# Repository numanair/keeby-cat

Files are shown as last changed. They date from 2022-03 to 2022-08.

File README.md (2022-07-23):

# Keeby Cat

This is the hardware repository for the Keeby Cat macropad. Developement is ongoing.

## Intro

Keeby Cat is a highly configurable macropad with multiple fader and knob layouts. The "standard" build features 3x4 keys with a rotary encoder and an 128x32 pixel OLED display. A full keyswitch build is 3x5 keys with the top row offset vertically by 0.25u. Up to five rotary encoders can be used in specified locations. One to three faders (linear potentiometers) can be used in place of the lower key columns.

## Firmware

Vial is the standard firmware for Keeby Cat as it allows key and encoder reassignment without recompiling firmware.
Firmware source is located here: [github.com/numanair/vial-qmk](https://github.com/numanair/vial-qmk/tree/vial/keyboards/returntoparadise/keeby_cat)  
**Note:** Firmware has not yet been completed for all variations. As such not all variants have been tested yet. However, the groundwork is there and it should not be too complicated to create these firmware variations.

## Layouts and Configurations

The default configuration is 3x4 keys with a single knob and an OLED screen.

The maximum keyswitch layout is 3x5.

### Rotary Encoder Knobs

Nine special key locations can accept encoder knobs, however only five knobs can be wired up at once.

Potential knob locations are:  
The left and right columns of the lower 4 keys, but with only one from each *row* being installed.
The top left corner.

### OLED Screen

An optional display can show layer information, key-states, and graphics. It replaces the top right pair of keyswitches.

## Cases

Two types of cases are available. The low-profile option is more minimal in material usage and features a 3-degree tilt. The high-profile case (`keeby_cat_case_retro-hi_v1.0.FCStd`) has a 5-degree tilt, but is actually slightly lower profile at the front. USB port placement on the high-profile case is currently more refined. It is designed for a Blue Pill board with a mid-mount micro USB port. These refinements will eventually be integrated into the low-profile case as well. To modify these CAD files, please use [realthunder's FreeCAD fork, stable build 2022.07.09.](https://github.com/realthunder/FreeCAD/releases/tag/2022.07.09-edge)

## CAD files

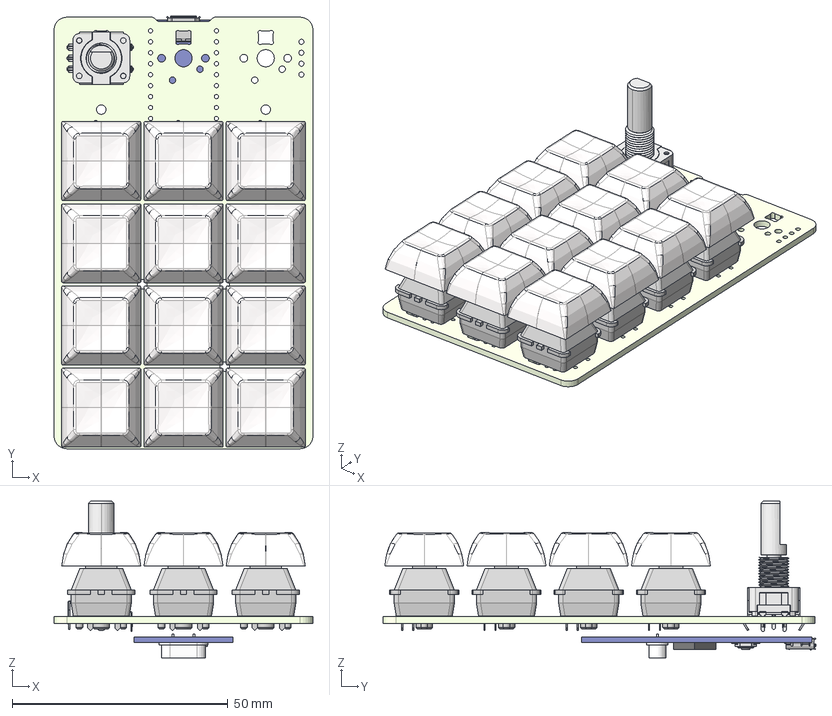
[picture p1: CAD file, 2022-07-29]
FreeCAD Assembly/keeby_cat_electronics_v1.0.FCStd
60.0 x 100.2 x 36.3 mm
Pcb_61fa
SW4_cherry_mx v1_b31d9dcab5e3 x 12
SW4_Keycap_adjusted v39_b31d9dcab5e3[2] x 24
EN4_PEC11-4220F-S0024_05183b338953 x 2
Oscillator_HC-49/S v1
STM32F103C8T6_BluePill_Board v6
STM32_LQFP48 v3
Tactile_SMD_5x5mm v1
micro_usb_socket v1

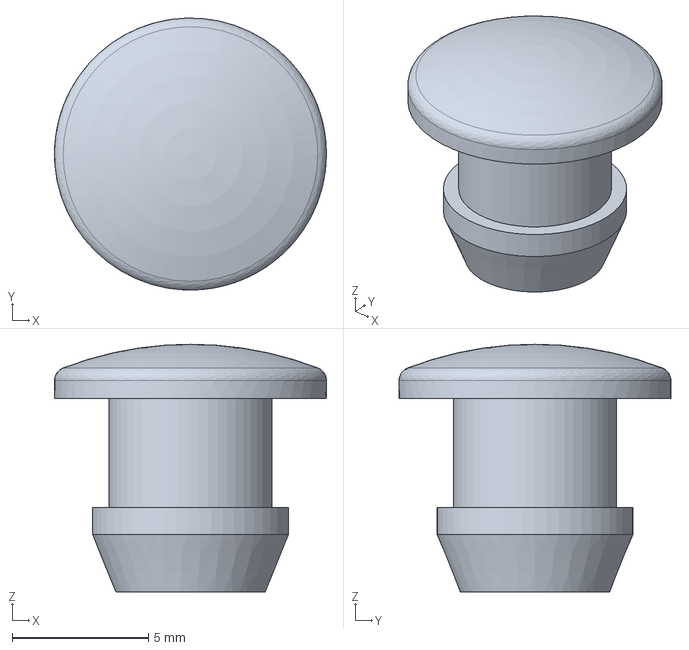
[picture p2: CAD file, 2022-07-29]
FreeCAD Assembly/silicone_stopper_foot.FCStd
10.00 x 10.00 x 9.10 mm

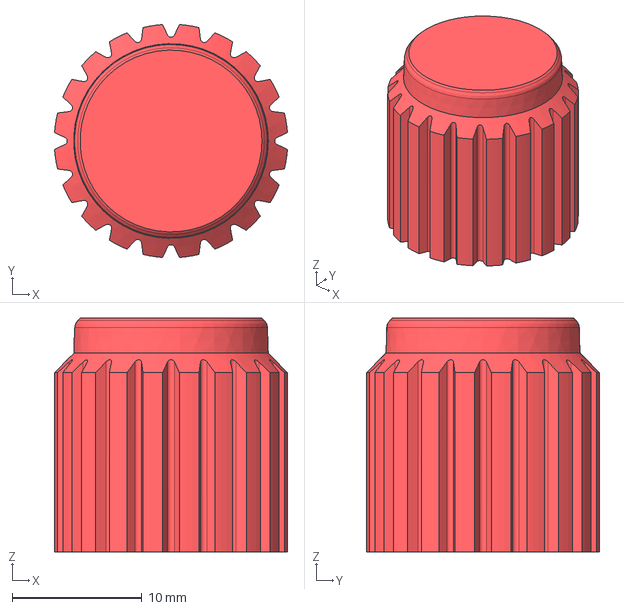
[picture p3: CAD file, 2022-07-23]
FreeCAD Assembly/knob_brute.FCStd
18.0 x 18.0 x 18.0 mm

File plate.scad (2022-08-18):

// include <NopSCADlib/core.scad>
include <NopSCADlib/lib.scad>
include <Chamfers-for-OpenSCAD/Chamfer.scad>

$fn=24;

plate_thick=5 - 0.2;
plate_thin=1.5;
chamfer_size=0.6; // not H
polyholes = false;

//pitch
key_unit=19.050;

overall_width=60;
overall_length=102.8625;

//array of positions
//0 = blank panel
//1 = keyswitch
//2 = encoder knob.
// Encoders can be in columns 1 and 3, but each row 1-4 can only have one at a time (per row).
// One exception: encoder cannot go in row 5 column 3.
//3 = fader. Can be anywhere in row 1
//4 = OLED. Goes in row 5, column 2+3.
//5 = empty. Tenporary solution
layout_matrix = [
 //row 1.
 [1,1,1],
 //row 2
 [1,1,1],
 //row 3
 [1,1,1],
 //row 4
 [1,1,1],
 //separator
 [0,0,0],
 //row 5 (top section)
 [2,4,1],
 ];

x_center = (key_unit*len(layout_matrix[0])-overall_width)/2;
y_center = (key_unit*(len(layout_matrix)-3/4)-overall_length)/2;

// keyswitch_plate();
// fader_plate();
main();

// j = y (row)
// i = x (column)
module main(){
  // intersection(){
 intersection(){
  difference(){
  union(){
  for ( i=[0:len(layout_matrix[0])-1]) {
   for ( j=[0:len(layout_matrix)-1]) {
    if(j<4){
     translate([i*key_unit,j*key_unit,0])
     // middle
     if(i==1){
      if(j>0){
       if(layout_matrix[0][i]==3){
        plate_gen(5);
       }
       else plate_gen(layout_matrix[j][i]);
       }
       else if(layout_matrix[j][i]==2){
        plate_gen(0);
       }
      else plate_gen(layout_matrix[j][i]);
     }
     else if(j==0){
      if(layout_matrix[j][i]==2){
       plate_gen(layout_matrix[j][i]);
      }
     else if (i==1) plate_gen(0);
     else plate_gen(layout_matrix[j][i]);
     }
     else if(layout_matrix[0][i]==3){
      plate_gen(5);
     }
     else if(layout_matrix[0][i]!=3){
      plate_gen(layout_matrix[j][i]);
     }
    }
    // separator
    else if(j==4){
     if(i==0){
     translate([i*key_unit,j*key_unit,0]) separator();
     }
    }
    // top row
    else if(j>4){
     if (i==2) {
      // checks for OLED in middle column 
      if (layout_matrix[5][1]==4) {
       plate_gen(5);
      }
      else 
      translate([i*key_unit,j*key_unit-key_unit*3/4,0])
      plate_gen(layout_matrix[j][i]);
     }
     else
     translate([i*key_unit,j*key_unit-key_unit*3/4,0])
     plate_gen(layout_matrix[j][i]);
    }
    bezel();
    }
   }
  } // end union
  pin_cut();
  // mounting holes go here
  mounting_holes();
  }
  fillet();
 } // end intersection 
// translate([0, overall_length-40, 0]) cube([overall_width,40,plate_thick]);
// }
}

//outer bezel
module bezel(){
 linear_extrude(plate_thick) difference(){
  translate([x_center,y_center,0])
  square([overall_width,overall_length]);
  translate([+0.1,+0.1,0]) square([key_unit*len(layout_matrix[0])-0.2,key_unit*len(layout_matrix)-key_unit*3/4-0.2]);
 }
}

//chooses correct plate
module plate_gen(plate=0){
 if(plate==0){
  blank_plate();
 }
 else if(plate==1){
  keyswitch_plate();
 }
 else if(plate==2){
  encoder_plate();
 }
 else if(plate==3){
  fader_plate();
 }
 else if(plate==4){
  OLED_plate();
 }
 else if(plate==5){
 }
 else{blank_plate();
 }
}

module blank_plate(){
  linear_extrude(plate_thick){
 square(key_unit);
 }
}

module keyswitch_plate(){
 inner_chamfer=1.3;
 difference(){
  linear_extrude(plate_thick) difference(){
   translate([-0.1,-0.1,0]) square(key_unit+0.2);
   // bool subtract tool:
   union(){
    translate([key_unit/2,key_unit/2,0]) square([14 + 0.1 + 0.3,14 + 0.4],true); // square
    translate([key_unit/2,key_unit/2-(5.8+3.1)/2]) square([15.6,3.1],true); // notch
    translate([key_unit/2,key_unit/2+(5.8+3.1)/2]) square([15.6,3.1],true); // notch
   }
  }
  // subtract to create recess
  translate([(key_unit-16)/2,(key_unit-16)/2,0]){
  chamferCube([16,16,plate_thick-plate_thin],[[0, 0, 0, 0], [0, 0, 0, 0], [1, 1, 1, 1]],inner_chamfer);
   }
  }
 }

module encoder_plate(){
 difference() {
  linear_extrude(plate_thick) difference(){
   translate([-0.1,-0.1,0]) square(key_unit+0.2);
   translate([key_unit/2,key_unit/2,0]){
   square([14.45,13.5],true);
   }
  }
  translate([key_unit/2,key_unit/2,0]){
   linear_extrude(plate_thick-plate_thin){
   square(16,true);
   }
  }
 }
}

module OLED_plate(){
 // 2x1 part. Origin in middle column, last row.
 difference() {
 linear_extrude(plate_thick)
 difference(){
 color([.3,.6,.6])
 square([key_unit*2,key_unit]);
 color([1,0,0])
// translate([0,(key_unit-(12.15+0.4))/2,0])
// square([38+0.2,12.15+0.4]);
 translate([key_unit*2-3.1,(key_unit-(12.15+0.4))/2,0])
 square([3.5,12.15+0.4]);
 }
 translate([key_unit*2-26,(key_unit-(12.15+0.4))/2,plate_thick-1.6])
 cube([26,12.15+0.4,1.65]);
 }
}

module fader_plate(){
 linear_extrude(plate_thick)
 difference(){
  translate([-0.1,-0.1,0])
  square([key_unit+0.2,key_unit*4+0.2]); // outer
  translate([key_unit/2,key_unit*4/2,0])
  square([10,75.1 + 0.35],true); // inner 
 }
}

module separator(){
 cube([3*key_unit,1/4*key_unit,plate_thick]);
}

// Pin headers
module pin_cut(){
 translate([x_center+21,y_center+overall_length-53-1.6,-0.1]) cube([3,53-1.6,plate_thick-plate_thin+0.1]);
 translate([x_center+overall_width-21-3,y_center+overall_length-53-1.6,-0.1]) cube([3,53-1.6,plate_thick-plate_thin+0.1]);
}

module fillet(){
 fillet_radius = 2;
 union(){
  difference(){
  translate([x_center,y_center,0])
  chamferCube([overall_width,overall_length,plate_thick],[[1, 1, 1, 1], [1, 1, 1, 1], [0, 0, 0, 0]],chamfer_size);

  translate([x_center,y_center,0]) cube([fillet_radius,fillet_radius,plate_thick]);
  translate([x_center+overall_width-fillet_radius,y_center,0]) cube([fillet_radius,fillet_radius,plate_thick]);
  translate([x_center,y_center+overall_length-fillet_radius,0]) cube([fillet_radius,fillet_radius,plate_thick]);
  translate([x_center+overall_width-fillet_radius,y_center+overall_length-fillet_radius,0]) cube([fillet_radius,fillet_radius,plate_thick]);
  }

  // Corners
  translate([x_center+fillet_radius,y_center+fillet_radius,0])
   chamferCylinder(r=fillet_radius,  h=plate_thick, ch=chamfer_size); // bottom left
  
  translate([x_center-fillet_radius+overall_width,y_center+fillet_radius,0])
   chamferCylinder(r=fillet_radius,  h=plate_thick, ch=chamfer_size); // bottom right
  
  translate([x_center+fillet_radius,y_center+overall_length-fillet_radius,0])
   chamferCylinder(r=fillet_radius,  h=plate_thick, ch=chamfer_size); // top left
  
  translate([x_center-fillet_radius+overall_width,y_center+overall_length-fillet_radius,0])
   chamferCylinder(r=fillet_radius,  h=plate_thick, ch=chamfer_size); // top right
  
 }
}

module screw_module(){
 screw_dia = 2 + 0.7;
 screw_head_dia = 3.51 + 0.6;
 if (polyholes == true) {
  cylinder(r=screw_dia/2, h=plate_thick, center=true);
  screw_polysink(M3_cs_cap_screw, h = 100, alt = false, sink = 0.4);
 }
 else{
  // screw_countersink(M2_cs_cap_screw, drilled = false);
  union(){
  translate([0,0,-(1.4/2+2.2)]){
    chamferCylinder(r=(screw_head_dia)/2,  h=2+.4+.7+2, ch=0.7);
  }
  //  cylinder(r=screw_dia/2, h=plate_thick*4, center=true);
  cylinder(r=screw_dia/2, h=plate_thick*4, center=true);
  }
 }
}

module mounting_holes() {
 // Upper 2
 translate([key_unit/2,key_unit*(4+1/8),plate_thick]) screw_module(); // Top left
 translate([2.5*key_unit,key_unit*(4+1/8),plate_thick]) screw_module(); // Top right
 // Lower 2
 translate([key_unit,key_unit*2,plate_thick]) screw_module(); // Bottom left
 translate([key_unit*2,key_unit*2,plate_thick]) screw_module(); // Bottom right
 
 // translate([key_unit,0,plate_thick]) screw_module(); // 
 // translate([key_unit*2,0,plate_thick]) screw_module(); // 

}

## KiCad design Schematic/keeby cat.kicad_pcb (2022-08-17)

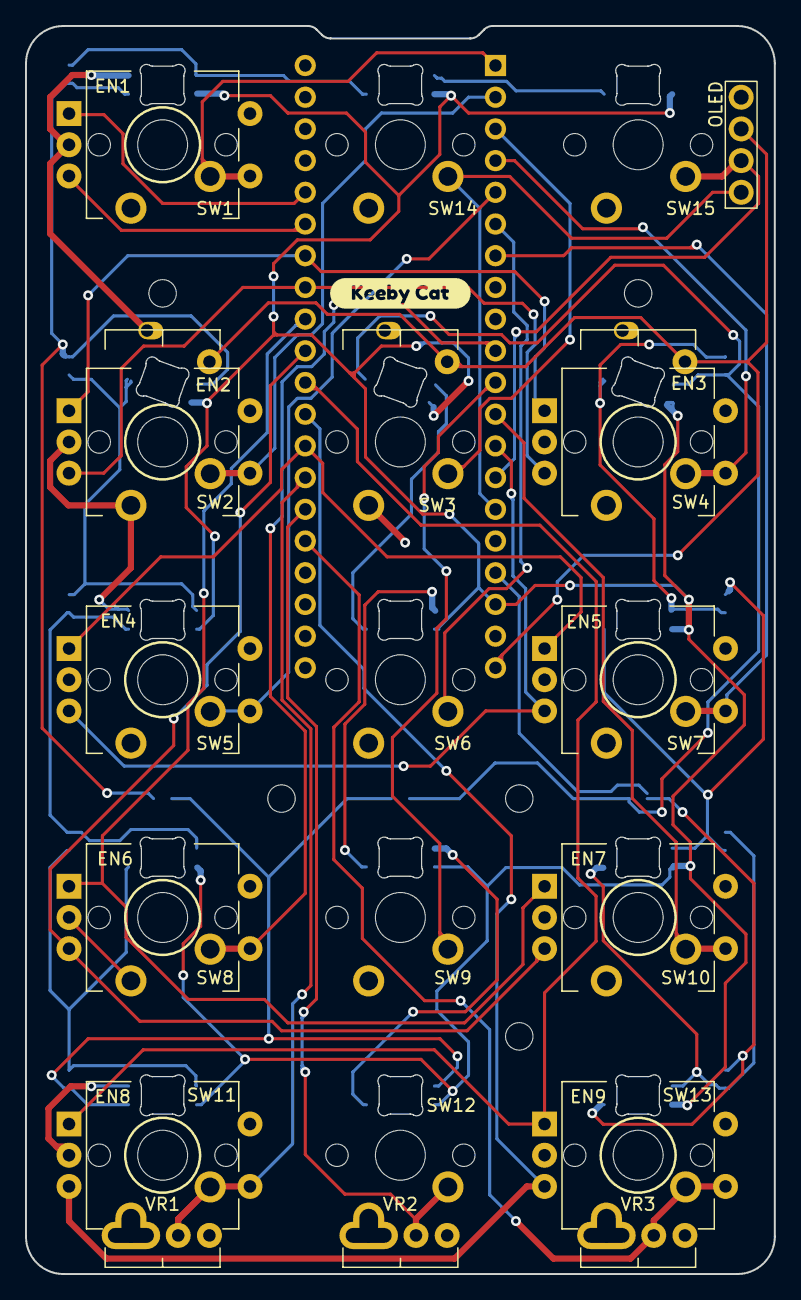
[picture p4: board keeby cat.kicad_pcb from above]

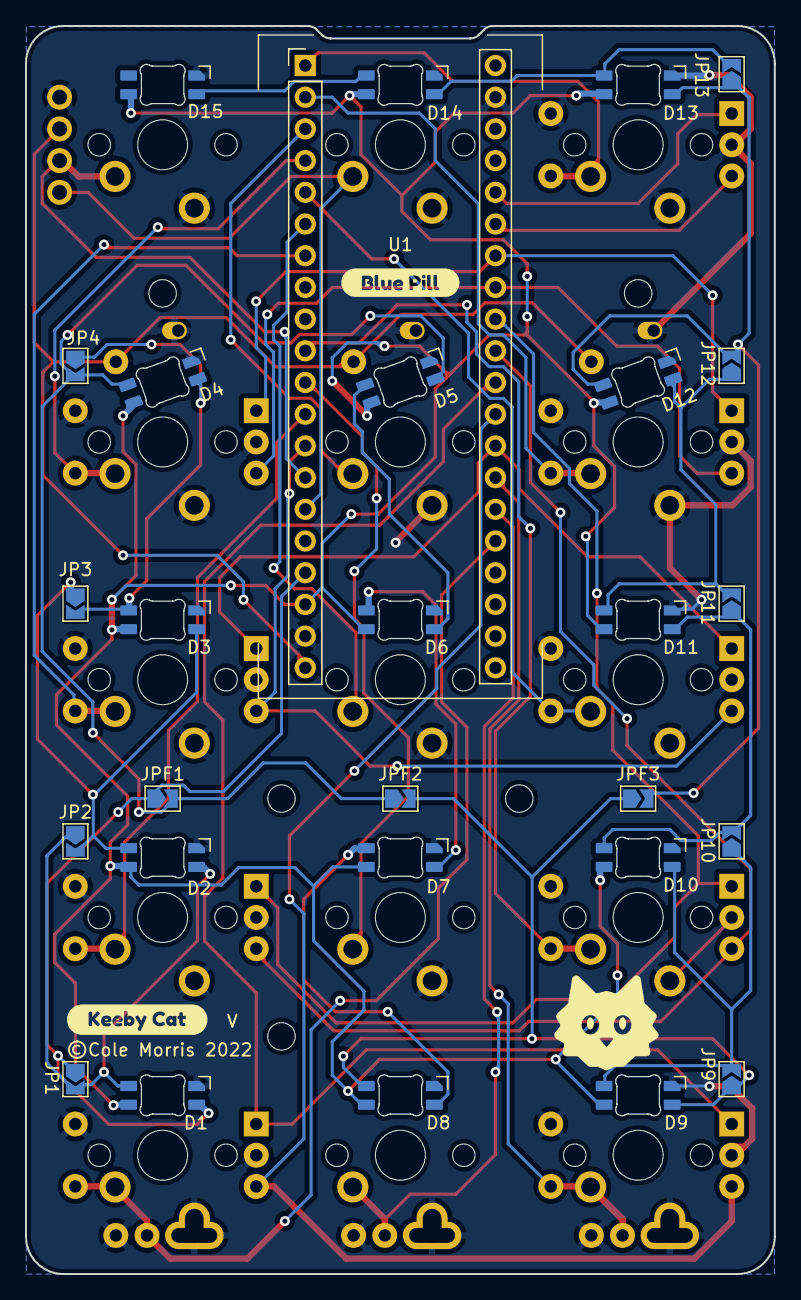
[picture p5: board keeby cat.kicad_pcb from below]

Board: 2 copper layers, 60.0 x 100.0 mm, 64 parts (15 on the bottom side), 43 nets.

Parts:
D1, D2, D3, D6, D7, D8, D9, D10, D11, D13, D14, D15: SK6812MINI-E; LED_MX_SK6812MINI-E
D4, D5, D12: SK6812MINI-E; LED_MX_SK6812MINI-E_rotated
EN1, EN2, EN3, EN4, EN5, EN6, EN7, EN8, EN9: RotaryEncoder_Switch; RotaryEncoder_Alps_EC11E-Switch_Vertical_H20mm_nomount_alt
H1, H2, H3, H4, H5: MountingHole; MountingHole_2.2mm_M2_DIN965
JP1, JP2, JP3, JP4, JP9, JP10, JP11, JP12, JP13: SolderJumper_2_Open; SolderJumper-2_P1.3mm_Open_TrianglePad1.0x1.5mm
JPF1, JPF2, JPF3: SolderJumper_2_Open; SolderJumper-2_P1.3mm_Open_TrianglePad1.0x1.5mm
OL1: OLED; OLED_v2
SW1, SW2, SW3, SW4, SW5, SW6, SW7, SW8, SW9, SW10, SW14, SW15: SW_Push; CherryMX_1u_north
SW11, SW12, SW13: SW_Push; CherryMX_1u_north_potcombo
U1: BluePill_V1.1; BluePill_bttn_basic
VR1, VR2, VR3: L_POT_Dual_PS60M_combo; PS60M Single-pin
kibuzzard-6226FF10, kibuzzard-6226FF10#2: G***; kibuzzard-6226FF10
kibuzzard-6227022E: G***; kibuzzard-6227022E

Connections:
+3V3: OL1.3 (VCC), U1.20 (3V3), VR1.3B, VR2.3B, VR3.3B
+5V: D1.1 (VDD), D2.1 (VDD), D3.1 (VDD), D4.1 (VDD), D5.1 (VDD), D6.1 (VDD), D7.1 (VDD), D8.1 (VDD), D9.1 (VDD), D10.1 (VDD), D11.1 (VDD), D12.1 (VDD), D13.1 (VDD), D14.1 (VDD), D15.1 (VDD), U1.18 (5V)
ENC1A: EN1.A, U1.36 (PB11)
ENC1B: EN1.B, U1.35 (PB10)
ENC2A: EN2.A, EN3.A, U1.34 (PB1)
ENC2B: EN2.B, EN3.B, U1.33 (PB0)
ENC3A: EN4.A, EN5.A, U1.28 (PA3)
ENC3B: EN4.B, EN5.B, U1.13 (PB5)
ENC4A: EN6.A, EN7.A, U1.32 (PA7)
ENC4B: EN6.B, EN7.B, U1.31 (PA6)
ENC5A: EN8.A, EN9.A, U1.30 (PA5)
ENC5B: EN8.B, EN9.B, U1.29 (PA4)
GND: D1.3 (GND), D2.3 (GND), D3.3 (GND), D4.3 (GND), D5.3 (GND), D6.3 (GND), D7.3 (GND), D8.3 (GND), D9.3 (GND), D10.3 (GND), D11.3 (GND), D12.3 (GND), D13.3 (GND), D14.3 (GND), D15.3 (GND), EN1.C, EN1.S2, EN2.C, EN2.S2, EN3.C, EN3.S2, EN4.C, EN4.S2, EN5.C, EN5.S2, EN6.C, EN6.S2, EN7.C, EN7.S2, EN8.C, EN8.S2, EN9.C, EN9.S2, OL1.4 (GND), SW1.2, SW2.2, SW3.2, SW4.2, SW5.2, SW6.2, SW7.2, SW8.2, SW9.2, SW10.2, SW11.2, SW12.2, SW13.2, SW14.2, SW15.2, U1.19 (GND), U1.39 (GND), VR1.1B, VR1.3, VR2.1B, VR2.3, VR3.1B, VR3.3
KEY1: EN1.S1, SW1.1, U1.1 (PB12)
KEY2: EN2.S1, SW2.1, U1.2 (PB13)
KEY3: SW3.1, U1.3 (PB14)
KEY4: EN3.S1, SW4.1, U1.4 (PB15)
KEY5: EN4.S1, SW5.1, U1.5 (PA8)
KEY6: SW6.1, U1.6 (PA9)
KEY7: EN5.S1, SW7.1, U1.7 (PA10)
KEY8: EN6.S1, SW8.1, U1.10 (PA15)
KEY9: SW9.1, U1.11 (PB3)
KEY10: EN7.S1, SW10.1, U1.12 (PB4)
KEY11-POT1: EN8.S1, SW11.1, U1.27 (PA2), VR1.2B
KEY12-POT2: SW12.1, U1.26 (PA1), VR2.2B
KEY13-POT3: EN9.S1, SW13.1, U1.25 (PA0), VR3.2B
LED_DATA: D1.4 (DIN), JP1.1 (A), JPF1.1 (A), U1.17 (PB9)
unnamed: D1.2 (DOUT), D2.4 (DIN), JP1.2 (B), JP2.1 (A)
unnamed: D2.2 (DOUT), D3.4 (DIN), JP2.2 (B), JP3.1 (A)
unnamed: D3.2 (DOUT), D4.4 (DIN), JP3.2 (B), JP4.1 (A)
unnamed: D4.2 (DOUT), D5.4 (DIN), JP4.2 (B), JPF1.2 (B), JPF2.1 (A)
unnamed: D5.2 (DOUT), D6.4 (DIN)
unnamed: D6.2 (DOUT), D7.4 (DIN)
unnamed: D7.2 (DOUT), D8.4 (DIN)
unnamed: D8.2 (DOUT), D9.4 (DIN), JP9.1 (A), JPF2.2 (B), JPF3.1 (A)
unnamed: D10.2 (DOUT), D11.4 (DIN), JP10.2 (B), JP11.1 (A)
unnamed: D9.2 (DOUT), D10.4 (DIN), JP9.2 (B), JP10.1 (A)
unnamed: D11.2 (DOUT), D12.4 (DIN), JP11.2 (B), JP12.1 (A)
unnamed: D12.2 (DOUT), D13.4 (DIN), JP12.2 (B), JP13.1 (A), JPF3.2 (B)
unnamed: D13.2 (DOUT), D14.4 (DIN), JP13.2 (B)
unnamed: D14.2 (DOUT), D15.4 (DIN)
SCL-SW: OL1.2 (SCL), SW15.1, U1.14 (PB6)
SDA-SW: OL1.1 (SDA), SW14.1, U1.15 (PB7)

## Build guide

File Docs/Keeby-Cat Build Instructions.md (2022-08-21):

# Keeby-Cat Build Instructions

The build order is critical to making a fully working Keeby Cat Macropad. Before soldering any parts together, check to make sure you have all components. Also ensure that the Blue Pill MCU is fully functional as it is not easy to replace once soldered in place. Some clone STM32's will function enough to output keypresses, but crash when trying to configure through VIAL.

## Steps

1. Determine layout (for LEDS)
2. Solder:
   1. LEDs
   2. Headers to *board* (not MCU). The solder goes on the top of the board. The plastic part of the headers is on the underside (with the Keeby Cat logo). Use the longer side of the legs and trim them after soldering. They do not need to be flush, just slightly trimmed.
   3. Encoder(s)
3. Combine the (3D printed) top plate with the key switches.
4. Install and solder
   1. Key switches: 3x spots over MCU must be done before soldering the MCU itself (SW3, SW6 and SW14).
   2. Potentiometers: most importantly POT2 must be done before the MCU. Fold the extra tabs flat. Note that one of the top legs must be straightened to fit in the PCB. After inserting the legs, fold the legs over flat so that they do not hit the blue pill later on.
   3. Solder MCU (Blue Pill) to the installed headers. The correct orientation has the MCU-side facing the ground when complete.
   4. OLED screen

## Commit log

2022-02-16 added my modification of marbastlib kicad library
2022-02-16 created Footprints library folder
2022-02-16 Add library files and update paths
    [LEDs.kicad_sch, keeb test board.kicad_pcb, keeb test board.kicad_sch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]
2022-02-17 updated libs, positioned jumpers
    [LEDs.kicad_sch, keeb test board.kicad_pcb, keeb test board.kicad_sch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]
2022-02-17 oled adjustment
    [keeb test board.kicad_pcb]
2022-02-17 modified silk outline of front pads
    [keeb test board.kicad_pcb]
2022-02-17 initial board routing
    [keeb test board.kicad_pcb, keeb test board.kicad_sch, key+encoder+combo.kicad_sch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]
2022-02-18 routing improvements
    [keeb test board.kicad_pcb]
2022-02-18 F.silk and via refinement
    [keeb test board.kicad_pcb]
2022-02-18 update silks and add copper
    [keeb test board.kicad_pcb]
2022-02-18 cleanup tracks
    [keeb test board.kicad_pcb]
2022-02-18 shrank board outline to 100mm max
    [keeb test board-B_Cu.gbr, keeb test board-B_Mask.gbr, keeb test board-B_Silkscreen.gbr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]
2022-02-18 adjusted routing around holes
    [keeb test board.kicad_pcb]
2022-02-18 rounded edge cuts for new 100mm size
    [keeb test board.kicad_pcb]
2022-02-18 move MCU downwards to better fit within new 100mm size
    [keeb test board.kicad_pcb]
2022-02-19 Fixed pin-sharing faders/keys
    [keeb test board.kicad_pcb, keeb test board.kicad_sch, key+encoder+combo.kicad_sch]
2022-02-19 removed extra via
    [keeb test board.kicad_pcb]
2022-02-19 first implementation of matrix
    [plate.scad]
2022-02-19 add fader to faceplate
    [plate.scad]
2022-02-20 split plate module out
    [plate.scad]
2022-02-20 more copper
    [keeb test board.kicad_pcb, keeb test board.kicad_sch]
2022-02-20 added bezel to plate
    [plate.scad]
2022-02-20 plate generator now overrides encoders in middle column
    [plate.scad]
2022-02-21 plate cleanup
    [plate.scad]
2022-02-21 more minor plate cleanup
    [plate.scad]
2022-02-25 Centered faders and rotated LEDs
    Experimental solution to make faders centered to lower 4 rows of keys/grid. Requires bending or trimming off an unused pin from the faders.
    [LEDs.kicad_sch, keeb test board.kicad_pcb, keeb test board.kicad_sch]
2022-02-27 Pin relief
    [plate.scad]
2022-02-27 routing and silkscreen improvements
    [keeb test board.kicad_pcb]
2022-02-27 Added fastener holes to plate
    [plate.scad]
2022-02-27 add option for polyholes countersink
    [plate.scad]
2022-03-08 routing and footprint fixes
    [keeb test board.kicad_pcb, keeb test board.kicad_sch]
2022-03-08 changed text layer for some footprints
2022-03-08 improved thin spots in ground plane, removed via
    also very small routing improvements
    [keeb test board.kicad_pcb]
2022-03-09 Corrected LED pinout again
2022-03-09 masked top pads for encoders
2022-03-09 LED pins fixed, lots of rerouting
    Corrected LED and routed accordingly. Lots of other misc, changes to improve routing.
    [keeb test board.kicad_pcb, keeb test board.kicad_sch]
2022-03-09 spreadsheet for LED matrix in QMK
    [LED matrix.ods]
2022-03-09 Plate: chamfered edges, other improvements
    [plate.scad]
2022-03-10 minor routing tweaks
    [keeb test board.kicad_pcb]
2022-03-10 adjusted silkscreen
    [keeb test board.kicad_pcb]
2022-03-10 refilled zones
    [keeb test board.kicad_pcb]
2022-03-10 renamed PCB project files
    [keeby cat.kicad_pcb, keeby cat.kicad_sch]
2022-03-17 added cat mascot and silkscreen
    [keeby cat.kicad_pcb]
2022-03-17 refilled ground plane zone
    [keeby cat-B_Cu.gbr, keeby cat-B_Mask.gbr, keeby cat-B_Silkscreen.gbr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]
2022-03-17 refill for plotting v1.0
    [keeby cat.kicad_pcb]
2022-03-17 plotted gerbers for v1.0
    [keeb test board-B_Cu.gbr, keeb test board-B_Mask.gbr, keeb test board-B_Silkscreen.gbr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]
2022-03-18 minor fix for board outline
    [keeby cat.kicad_pcb]
2022-03-28 adjust schematic graphics
    [keeby cat.kicad_sch, key+encoder+combo.kicad_sch, key+encoder.kicad_sch]
2022-03-29 preview of back of board using PcbDraw
2022-04-13 Plate: Simplified some centering and adjusted holes
    [plate.scad]
2022-05-05 LED matrix file changes for alternate builds
    [LED matrix.ods]
2022-05-05 Base low-profile case
2022-06-29 knob prototyping
    [knob brute.FCStd]
2022-07-17 Increase clearance on the top plate
    Clearance for keyswitches has been increased to help compensate for too much 1st layer squish
    [plate.scad]
2022-07-17 Add OLED step and fix paths
    [keeby cat.kicad_pcb]
2022-07-17 remove redundant STEP model
    [keeby cat.kicad_pcb]
2022-07-18 removed large STEP from pcb
    [keeby cat linked case.FCStd, keeby cat.kicad_pcb, keeby_cat_case_v1.0.FCStd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]
2022-07-23 Add retro-hi case assembly
    High-profile case designed with FreeCAD linkstage3 daily 20220709
    [keeby cat linked case.FCStd, keeby_cat_case_v1.0.FCStd, keeby_cat_electronics_v1.0.FCStd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]
2022-07-23 moved PCB grid origin for better CAD import
    [keeby cat.kicad_pcb]
2022-07-29 removed extra knob CAD file
    [knob brute.FCStd]
2022-07-29 Update case CAD
    Refined some geometry
    Added small chamfers and fillets to sharp edges on bottom of case
    Recreated constraints and locked other parts
    [keeby_cat_electronics_v1.0.FCStd, silicone_stopper_foot.FCStd]
2022-07-29 Apply Spreadsheet value to model
    Make screw holes based on spreadsheet value
    [keeby_cat_electronics_v1.0.FCStd]
2022-08-11 Move kicad schematic
    [LEDs.kicad_sch, keeby cat.kicad_pcb, keeby cat.kicad_sch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]
2022-08-17 add missing logic to plate.scad
    add missing logic for keyswitches in the top row
    [plate.scad]
2022-08-17 Move libraries to KiCAD schematic folder
    And update Blue Pill 3D CAD model in board
    [keeby cat-B_Cu.gbr, keeby cat-B_Mask.gbr, keeby cat-B_Silkscreen.gbr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]
2022-08-18 add more clearance for screw head to plate
    [plate.scad]

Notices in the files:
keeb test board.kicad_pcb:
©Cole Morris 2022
